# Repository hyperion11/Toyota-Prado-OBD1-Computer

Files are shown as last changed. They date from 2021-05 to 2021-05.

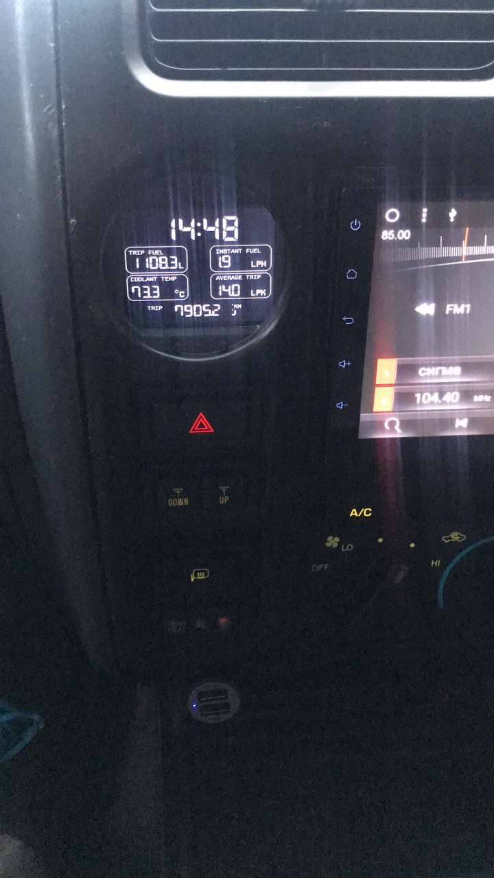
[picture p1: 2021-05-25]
source/TOBD1_STM32/problems1.jpg

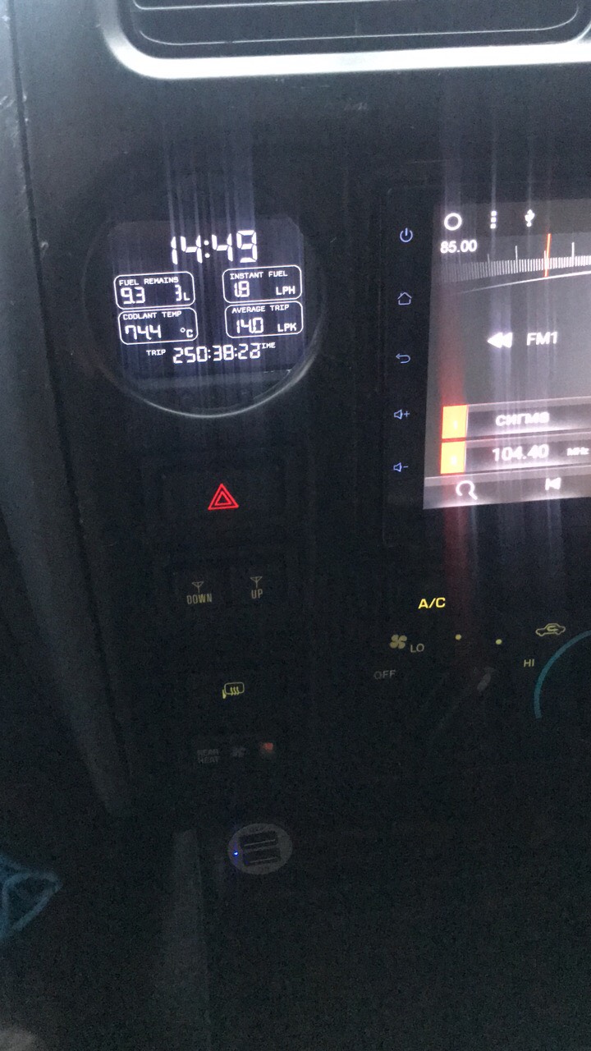
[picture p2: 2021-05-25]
source/TOBD1_STM32/problems2.jpg

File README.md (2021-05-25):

# Toyota-Prado-OBD1-Computer
OBD1 Car computer for Toyota land Cruiser Prado 90 95 1997-2002 5VZ-FE or 3RZ-FE engine

For "Thanks!" you can give me a "coffee" :)

https://www.tinkoff.ru/rm/degtyarev.aleksey35/kHApi80257

or

https://paypal.me/alekseydegtyarev1986?locale.x=ru_RU

BILL OF MATERIALS:

Maple Mini STM32 Dev board http://alii.pub/5snybc

2.4' ILI9341 SPI TFT Screen with flex cable w\o touch http://alii.pub/5snyhd

Capacitors:
22uF 0805 5pcs
http://alii.pub/5snzpw

1uF 0805 2pcs
http://alii.pub/5snzpw

0.1uF 0805 7pcs
http://alii.pub/5snzpw

3.3nF 0805 1pcs
http://alii.pub/5snzpw

100uF 0805 1pcs
http://alii.pub/5snzvc

Diode DO214
http://alii.pub/5so00s

ADC    B4B-ZRROUND           B4B-ZRROUND            B4B-ZR                JST-ZH Connector                                                                                       

BT2                          BATTERY                BATTCOM_20MM_VERTICAL Battery - Single Cell                                                                                 

PTC Fuse 1206 0.7-1A
http://alii.pub/5so034
 
FRAM MB85RC04VPNF 3.3v
http://alii.pub/5so077

LN6206                       MCP1700                SOT23                                                                                                                     LN6206P302MR-G                                                                                                                                                                                                      
Q1     PDTC143XT             MUN2211T1              SC59-BEC              NPN Bias Resistor Transistor                                                                                                                0                                                                                                                                                                           
Q2     PDTA143ZT             MUN2111T1              SC59-BEC              PNP Bias Resistor Transistor                                                                                                                0                                                                                                                                                                           
R1     33K                   R-EU_R0805             R0805                 RESISTOR, European symbol                                                                                                                                                                                                                                                                                               
R3     4                     R-EU_R0805             R0805                 RESISTOR, European symbol                                                                                                                                                                                                                                                                                               
R4     PHOTORESPDV-P9        PHOTORESPDV-P9         PDV-P9XXX             Photoresistor                                                                                                                                                                                                                                                                                                           
R10    20K                   R-EU_R0805             R0805                 RESISTOR, European symbol                                                                                                                                                                                                                                                                                               
R11    6.8K                  R-EU_R0805             R0805                 RESISTOR, European symbol                                                                                                                                                                                                                                                                                               
R12    3.3K                  R-EU_R0805             R0805                 RESISTOR, European symbol                                                                                                                                                                                                                                                                                               
R13    10K                   R-EU_R0805             R0805                 RESISTOR, European symbol                                                                                                                                                                                                                                                                                               
R31    4.7K                  R-EU_R0805             R0805                 RESISTOR, European symbol                                                                                                                                                                                                                                                                                               
R32    4.7K                  R-EU_R0805             R0805                 RESISTOR, European symbol                                                                                                                                                                                                                                                                                               
R38    100                   R-EU_R0805             R0805                 RESISTOR, European symbol                                                                                                                                                                                                                                                                                               
RN1    10K                   RN2_EU-4               CTS-744*083           Chip Resistor Array's from various manufactures                                                     CRA064RJ10K0E04Z                                                                                                                                                                                                    
RN2    2.2K                  RN2_EU-4               CTS-744*083           Chip Resistor Array's from various manufactures                                                     CRA064RJ10K0E04Z                                                                                                                                                                                                    
RN3    10K                   RN2_EU-4               CTS-744*083           Chip Resistor Array's from various manufactures                                                     CRA064RJ10K0E04Z                                                                                                                                                                                                    
RN4    2.2K                  RN2_EU-4               CTS-744*083           Chip Resistor Array's from various manufactures                                                     CRA064RJ10K0E04Z                                                                                                                                                                                                    
S1     DTSM-6                DTSM-6                 DTSM-6                                                                                                                                                                                                                                                                                                                                        
S2     DTSM-6                DTSM-6                 DTSM-6                                                                                                                                                                                                                                                                                                                                        
S3     DTSM-6                DTSM-6                 DTSM-6                                                                                                                                                                                                                                                                                                                                        
S4     DTSM-6                DTSM-6                 DTSM-6                                                                                                                                                                                                                                                                                                                                        
S5     DTSM-6                DTSM-6                 DTSM-6                                                                                                                                                                                                                                                                                                                                        
SERIAL B4B-ZRROUND           B4B-ZRROUND            B4B-ZR                JST-ZH Connector                                                                                                                                                                                                                                                                                                        
SG2    F/QMBIII              F/QMBIII               F/QMBIII              BUZZER Source: Buerklin                                                                                                unknown    unknown   1                                                                                                                                                                                                                                                                                                                          
U$2    JUSHUOAFC08-S18FCA-00 JUSHUOAFC08-S18FCA-00  JUSHUOAFC08-S18FCA-00                                                                                                     AFC08-S18FCA-00                                                                                                                                                                                                     
U$3    main                  B5B-ZRLONG             B5B-ZR-LONG           JST-ZH Connector                                                                                                                                                                                                                                                                                                        
U$4    MINI-DC-DC-3AV        MINI-DC-DC-3AV         MINI-DC-DC-3AV                                                                                                                                                                                                                                                                                                                                
U$5    ADC-4CH-ADS1115       ADC-4CH-ADS1115        ADC-4CH-ADS1115       4 Channel 16-Bit Analog-to-Digital Converter based on ADS1115 chip

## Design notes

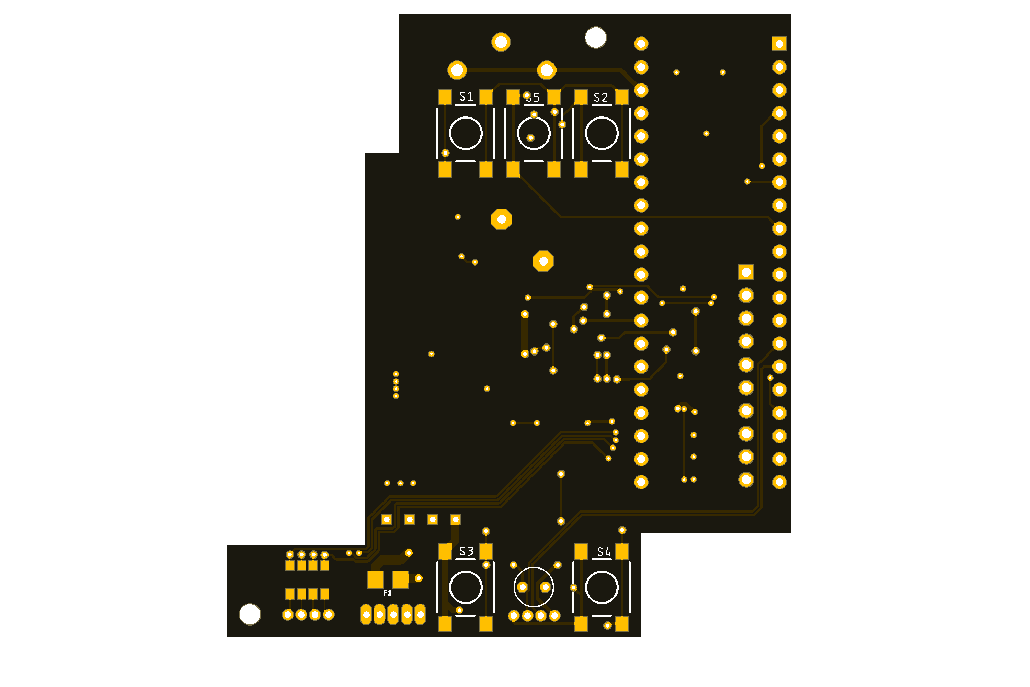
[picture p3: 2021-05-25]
Schematic/v2.4/TOBD_STM32b.png

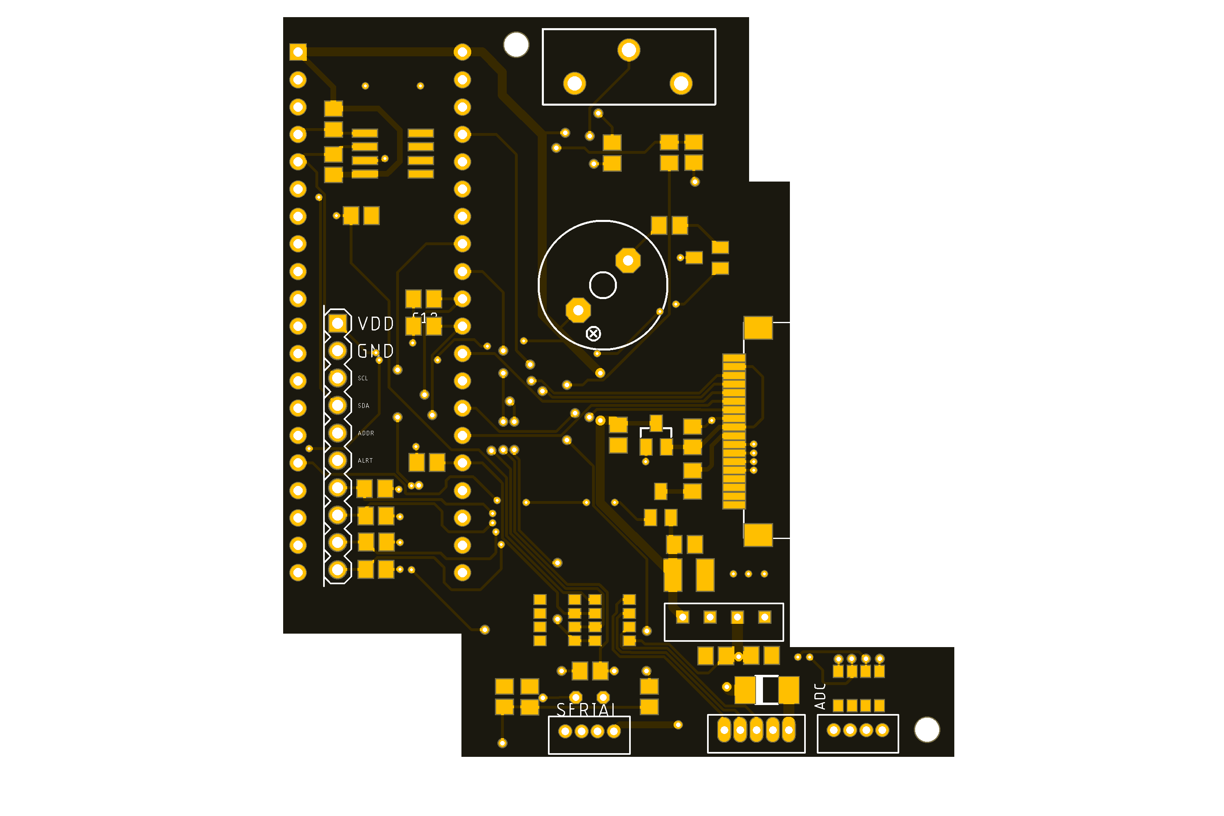
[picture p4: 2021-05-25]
Schematic/v2.4/TOBD_STM32е.png

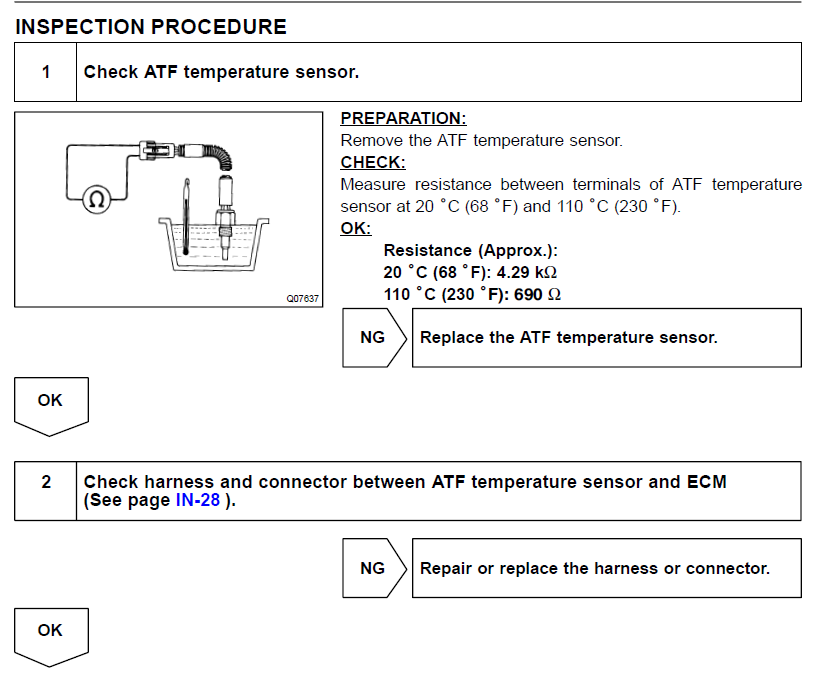
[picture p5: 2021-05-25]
source/TOBD1_STM32/atf_temp_sensor_2.png

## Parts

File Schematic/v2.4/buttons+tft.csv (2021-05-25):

C2 | 1uF | C-EUC0805 | C0805 | CAPACITOR, European symbol |  | Samsung Electro-Mechanics | CL21F105ZOFNNNE |  |  | 88 | C | https://lcsc.com/product-detail/Multilayer-Ceramic-Capacitors-MLCC-SMD-SMT_SAMSUNG_CL21F105ZOFNNNE_1uF-105-80-20-16V_C16834.html
C8 | 0.1uF | C-EUC0805 | C0805 | CAPACITOR, European symbol |  | Samsung Electro-Mechanics | CL21F104ZBCNNNC |  |  | 88 | C | https://lcsc.com/product-detail/Multilayer-Ceramic-Capacitors-MLCC-SMD-SMT_SAMSUNG_CL21F104ZBCNNNC_100nF-104-80-20-50V_C1760.html
C9 | 100uF | C-EUC1210K | C1210K | CAPACITOR, European symbol | C88154 | Murata Electronics | GRM32ER60J107ME20L |  |  |  |  | https://lcsc.com/product-detail/Multilayer-Ceramic-Capacitors-MLCC-SMD-SMT_muRata_GRM32ER60J107ME20L_100uF-107-20-6-3V_C88154.html
C10 | 22uF | C-EUC0805 | C0805 | CAPACITOR, European symbol | C45783 | Samsung Electro-Mechanics | CL21A226MAQNNNE |  |  |  |  | https://lcsc.com/product-detail/Multilayer-Ceramic-Capacitors-MLCC-SMD-SMT_Samsung-Electro-Mechanics-CL21A226MAQNNNE_C45783.html
C18 | 3.3nF | C-EUC0805 | C0805 | CAPACITOR, European symbol |  |  |  |  |  | 88 | C
IC4 | MB85RC04VPNF | 24C04ASN | SO-08 | Serial EEPROM |  |  |  | unknown | unknown | 0
LN6206 |  | MCP1700 | SOT23 |  |  |  | LN6206P332MR-G
RN1 | 10K | RN2_EU-4 | CTS-744*083 | Chip Resistor Array's from various manufactures |  |  | CRA064RJ10K0E04Z
RN2 | 2.2K | RN2_EU-4 | CTS-744*083 | Chip Resistor Array's from various manufactures |  |  | CRA064RJ10K0E04Z
U$2 | JUSHUOAFC08-S18FCA-00 | JUSHUOAFC08-S18FCA-00 | JUSHUOAFC08-S18FCA-00 |  |  |  | AFC08-S18FCA-00

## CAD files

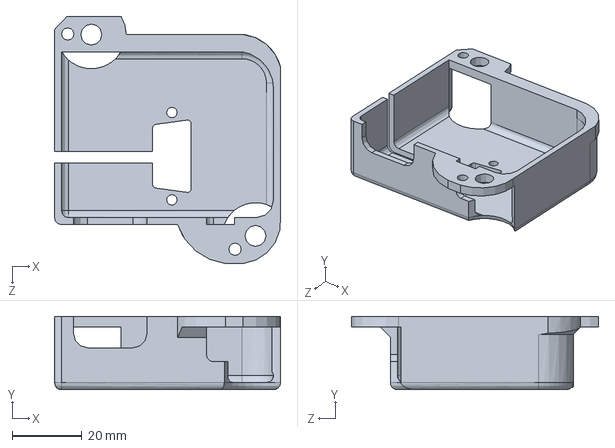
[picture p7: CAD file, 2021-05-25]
BK Model/Assem2.SLDASM
64.7 x 21.0 x 70.7 mm

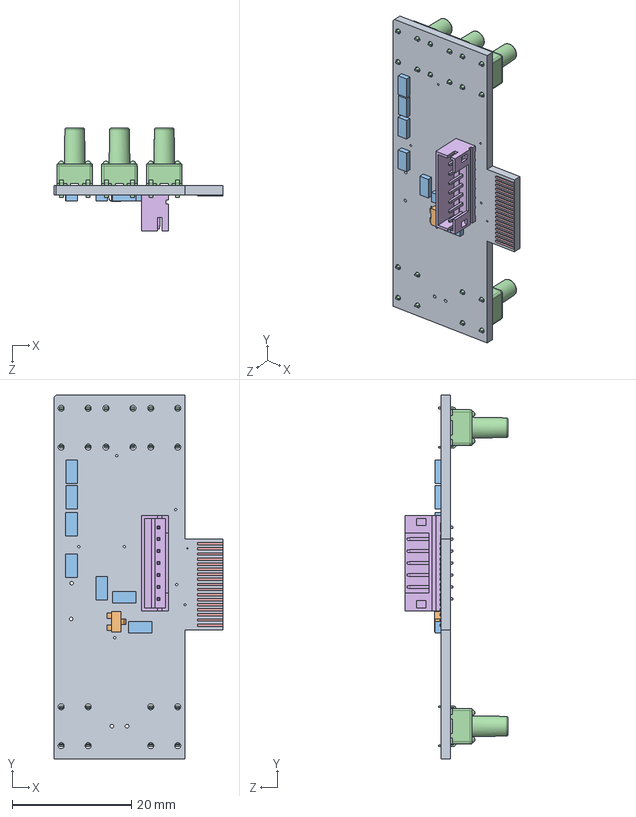
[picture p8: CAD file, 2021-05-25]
BK Model/buttons+tft.SLDASM
28.3 x 61.0 x 17.2 mm
buttons+tft
sot23_4210037
R0805_R0805 x 7
Tact DIP 6x6 x 5
18x08
Header Socket 2_0 7x

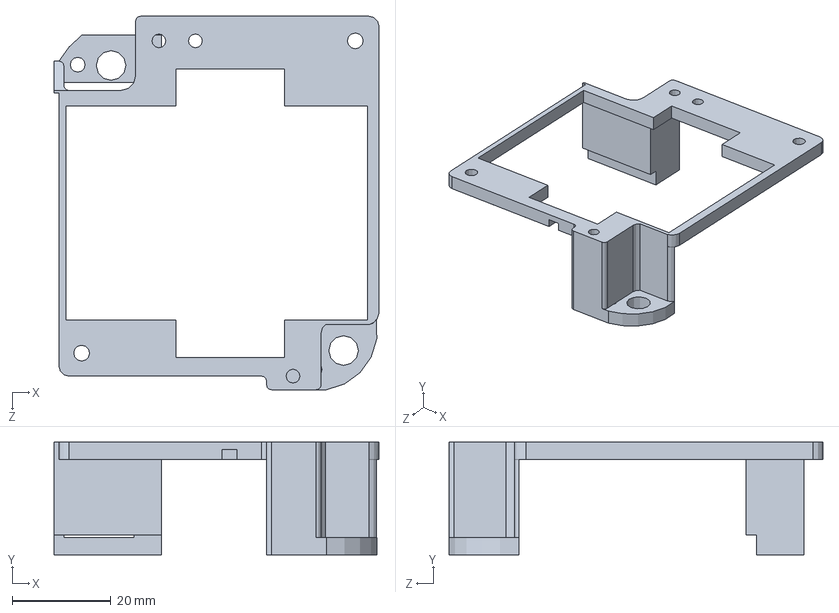
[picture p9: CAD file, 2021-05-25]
BK Model/main_box.SLDPRT
65.7 x 22.8 x 75.5 mm

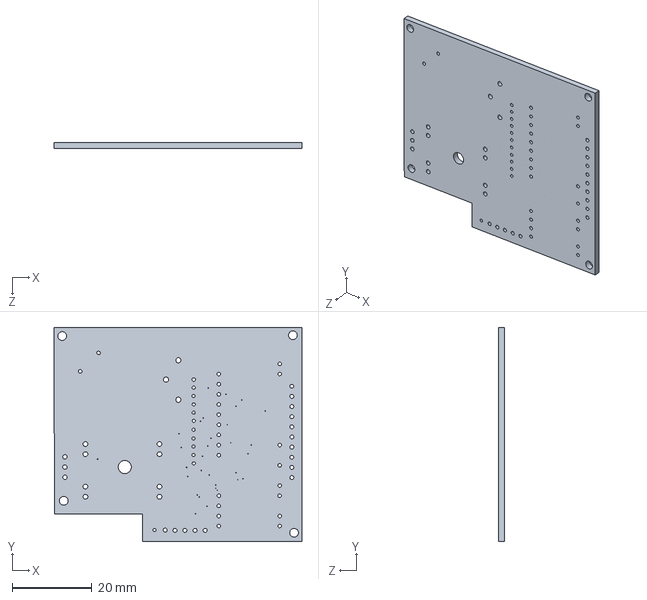
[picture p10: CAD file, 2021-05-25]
BK Model/pcb_top.SLDASM
62.1 x 53.7 x 1.60 mm

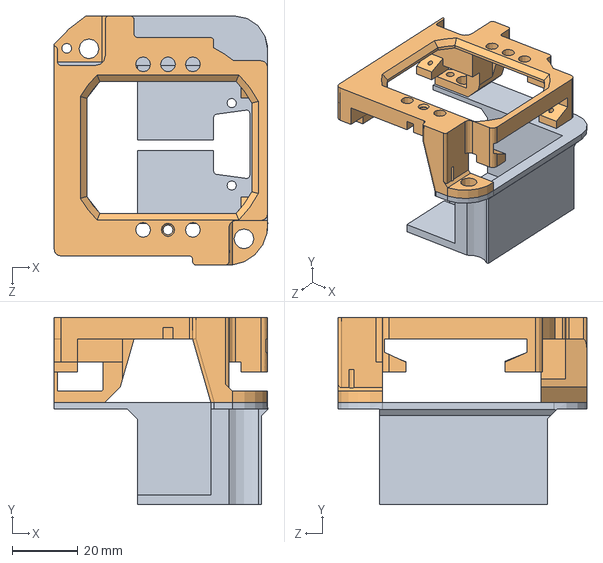
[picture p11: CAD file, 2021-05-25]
BK Model/Assem1.SLDASM
64.8 x 56.8 x 75.5 mm
крепеж_дисплея_top_v2.3
крепеж_дисплея_v2.3

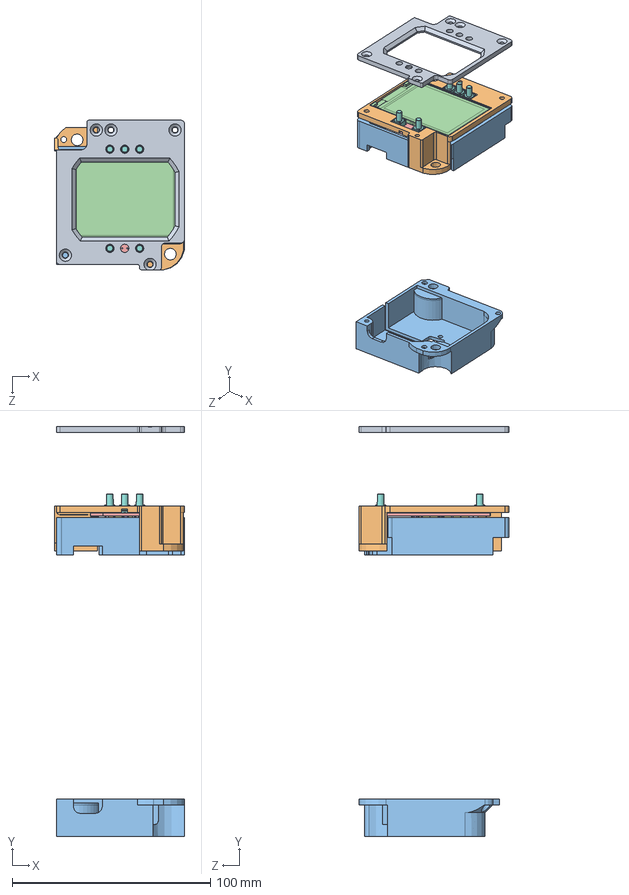
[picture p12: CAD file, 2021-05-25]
BK Model/Assem3.SLDASM
65.8 x 206.7 x 75.5 mm
front_shield
main_box
pcb_shield
2.4in TFT(Without Glass)- Reverse Mount
buttons+tft
sot23_4210037
R0805_R0805 x 7
Tact DIP 6x6 x 5
18x08
Header Socket 2_0 7x
крепеж_дисплея_top_v2.4_clean_remake

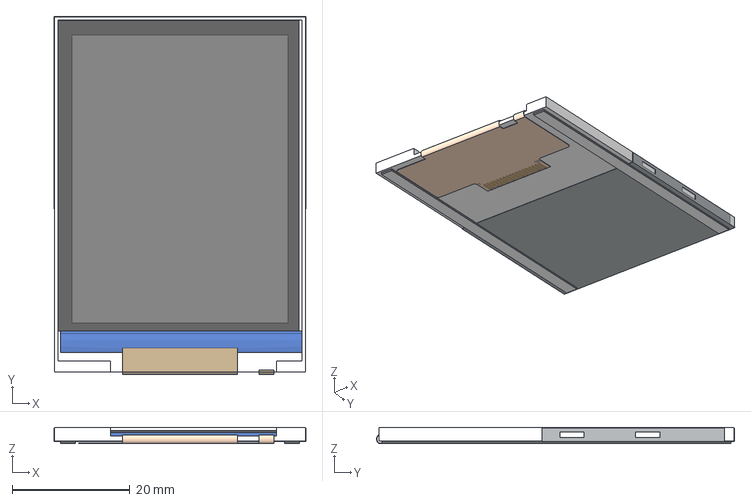
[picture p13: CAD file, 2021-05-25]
BK Model/2-4in-tft-module-1.snapshot.10/2.4in TFT(Without Glass)- Tucked Cable.stp
42.7 x 60.8 x 2.74 mm

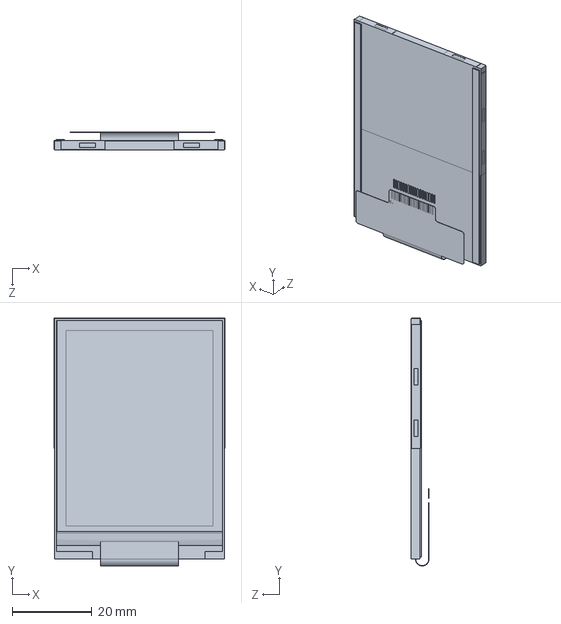
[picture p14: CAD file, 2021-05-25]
BK Model/2.4in TFT(Without Glass)- Reverse Mount.SLDPRT
42.7 x 62.1 x 4.60 mm

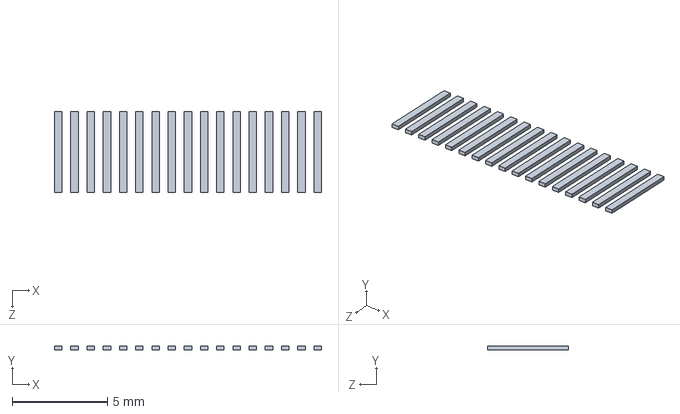
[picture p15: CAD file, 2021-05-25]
BK Model/18x08.SLDPRT
14.0 x 0.2 x 4.23 mm

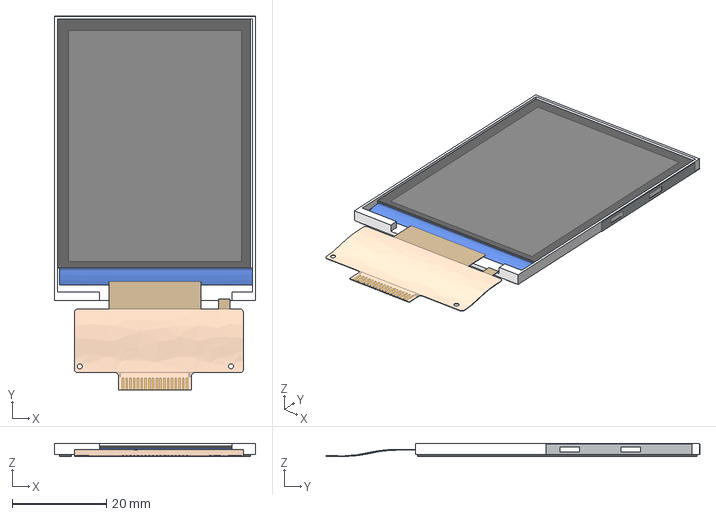
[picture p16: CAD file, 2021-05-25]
BK Model/2-4in-tft-module-1.snapshot.10/2.4in TFT(Without Glass)- Flat Mount.stp
42.7 x 79.4 x 2.74 mm

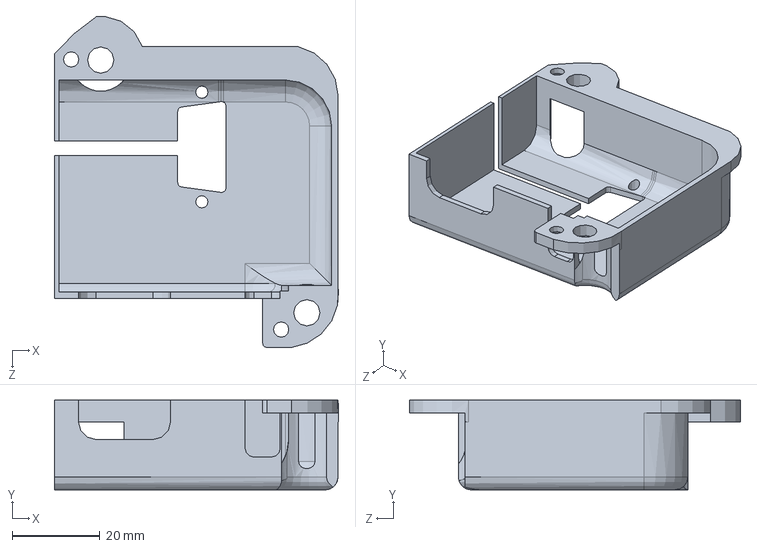
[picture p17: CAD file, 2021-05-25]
BK Model/крепеж_дисплея_top_v2.4.SLDPRT
64.8 x 20.5 x 75.5 mm

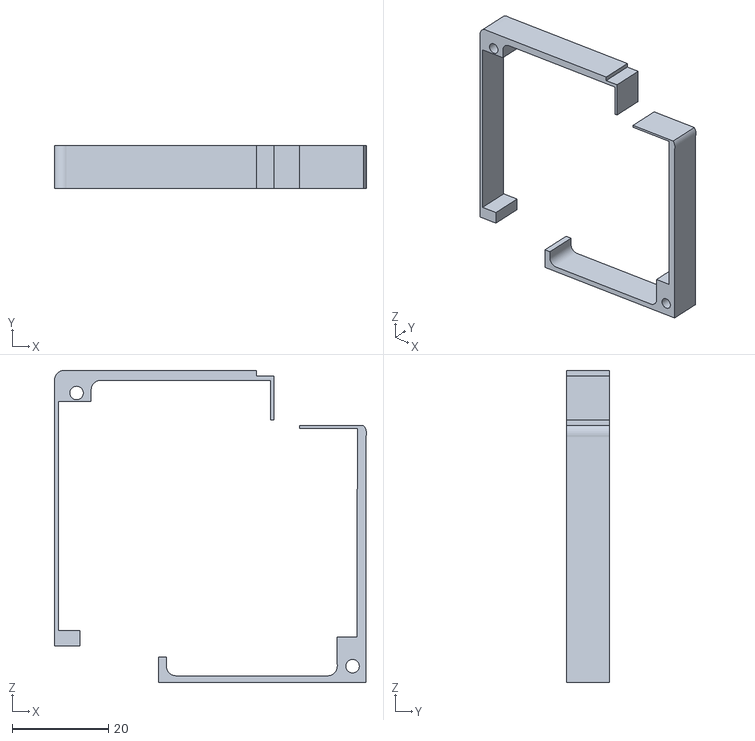
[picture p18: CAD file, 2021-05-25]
BK Model/2.STL
64.8 x 9.00 x 64.8

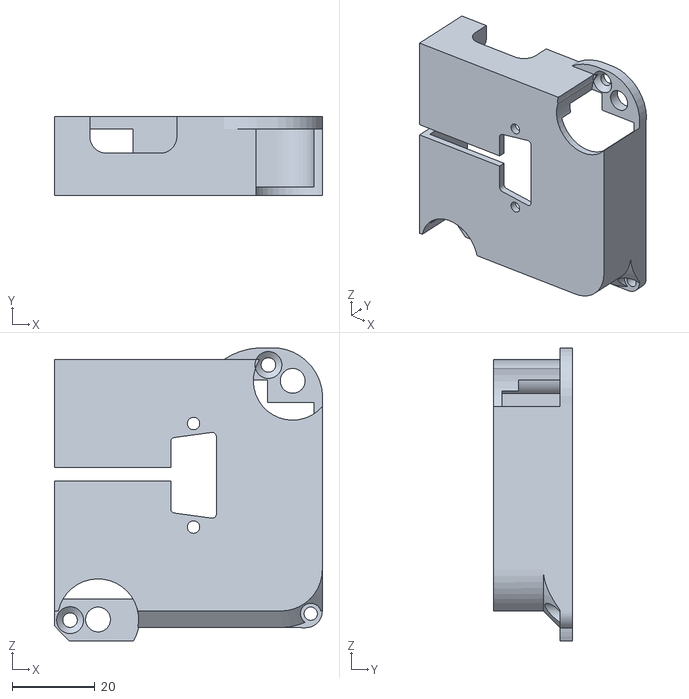
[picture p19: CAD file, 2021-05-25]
BK Model/1.STL
64.8 x 19.0 x 70.7

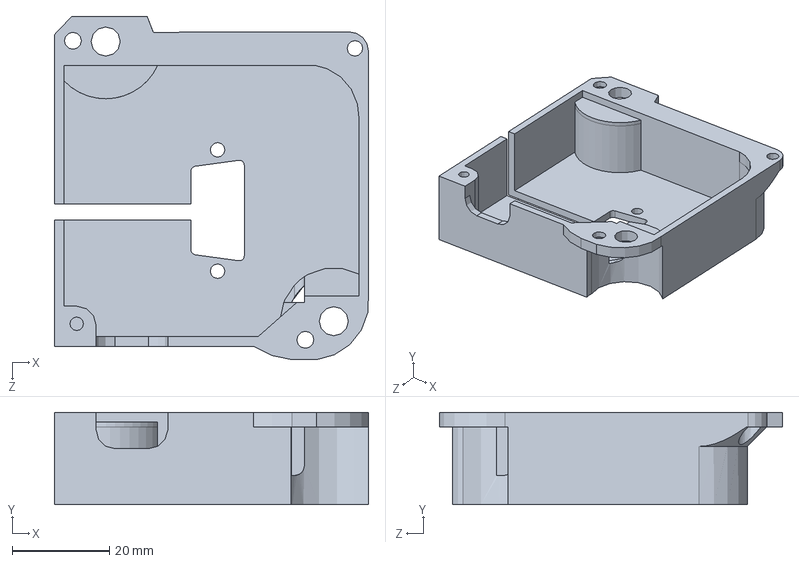
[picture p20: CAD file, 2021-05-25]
BK Model/крепеж_дисплея_top_v2.4_clean_remake.SLDPRT
64.7 x 19.0 x 70.7 mm

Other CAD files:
BK Model/2-4in-tft-module-1.snapshot.10/2.4in TFT(Without Glass)- Reverse Mount.stp
BK Model/крепеж_дисплея_v2.3.STEP
BK Model/крепеж_дисплея_1_v4.SLDPRT
BK Model/front_shield.SLDPRT
BK Model/front_shield.STL
BK Model/main_box.STL
BK Model/pcb_shield.SLDPRT
BK Model/pcb_shield.STL
BK Model/крепеж_дисплея_1_v1.SLDPRT
BK Model/крепеж_дисплея_1_v1.STL
BK Model/крепеж_дисплея_1_v2.SLDPRT
BK Model/крепеж_дисплея_1_v2.STL
BK Model/крепеж_дисплея_1_v3.SLDPRT
BK Model/крепеж_дисплея_1_v3.STL
BK Model/крепеж_дисплея_1_v4.STL
BK Model/крепеж_дисплея_top_v2.2.SLDPRT
BK Model/крепеж_дисплея_top_v2.2.STL
BK Model/крепеж_дисплея_top_v2.3.SLDPRT
BK Model/крепеж_дисплея_top_v2.3.STL
BK Model/крепеж_дисплея_top_v2.4.STL
BK Model/крепеж_дисплея_top_v2.4_clean_remake.STL
BK Model/крепеж_дисплея_v2.1.SLDPRT
BK Model/крепеж_дисплея_v2.1.STL
BK Model/крепеж_дисплея_v2.2.SLDDRW
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

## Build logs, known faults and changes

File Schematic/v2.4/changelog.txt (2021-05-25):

v 2.1
1. Пофикшен земляной пин для платы TFT 
2. Перенесен пин BUT_ARRAY из под DC-DC
3. Фикс reset pina tft дисплея

v2.2
1. Добавлен фоторезистор на плату кнопок

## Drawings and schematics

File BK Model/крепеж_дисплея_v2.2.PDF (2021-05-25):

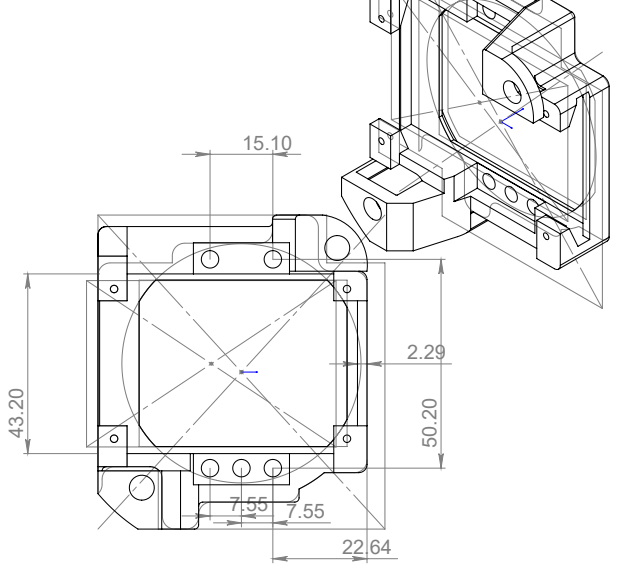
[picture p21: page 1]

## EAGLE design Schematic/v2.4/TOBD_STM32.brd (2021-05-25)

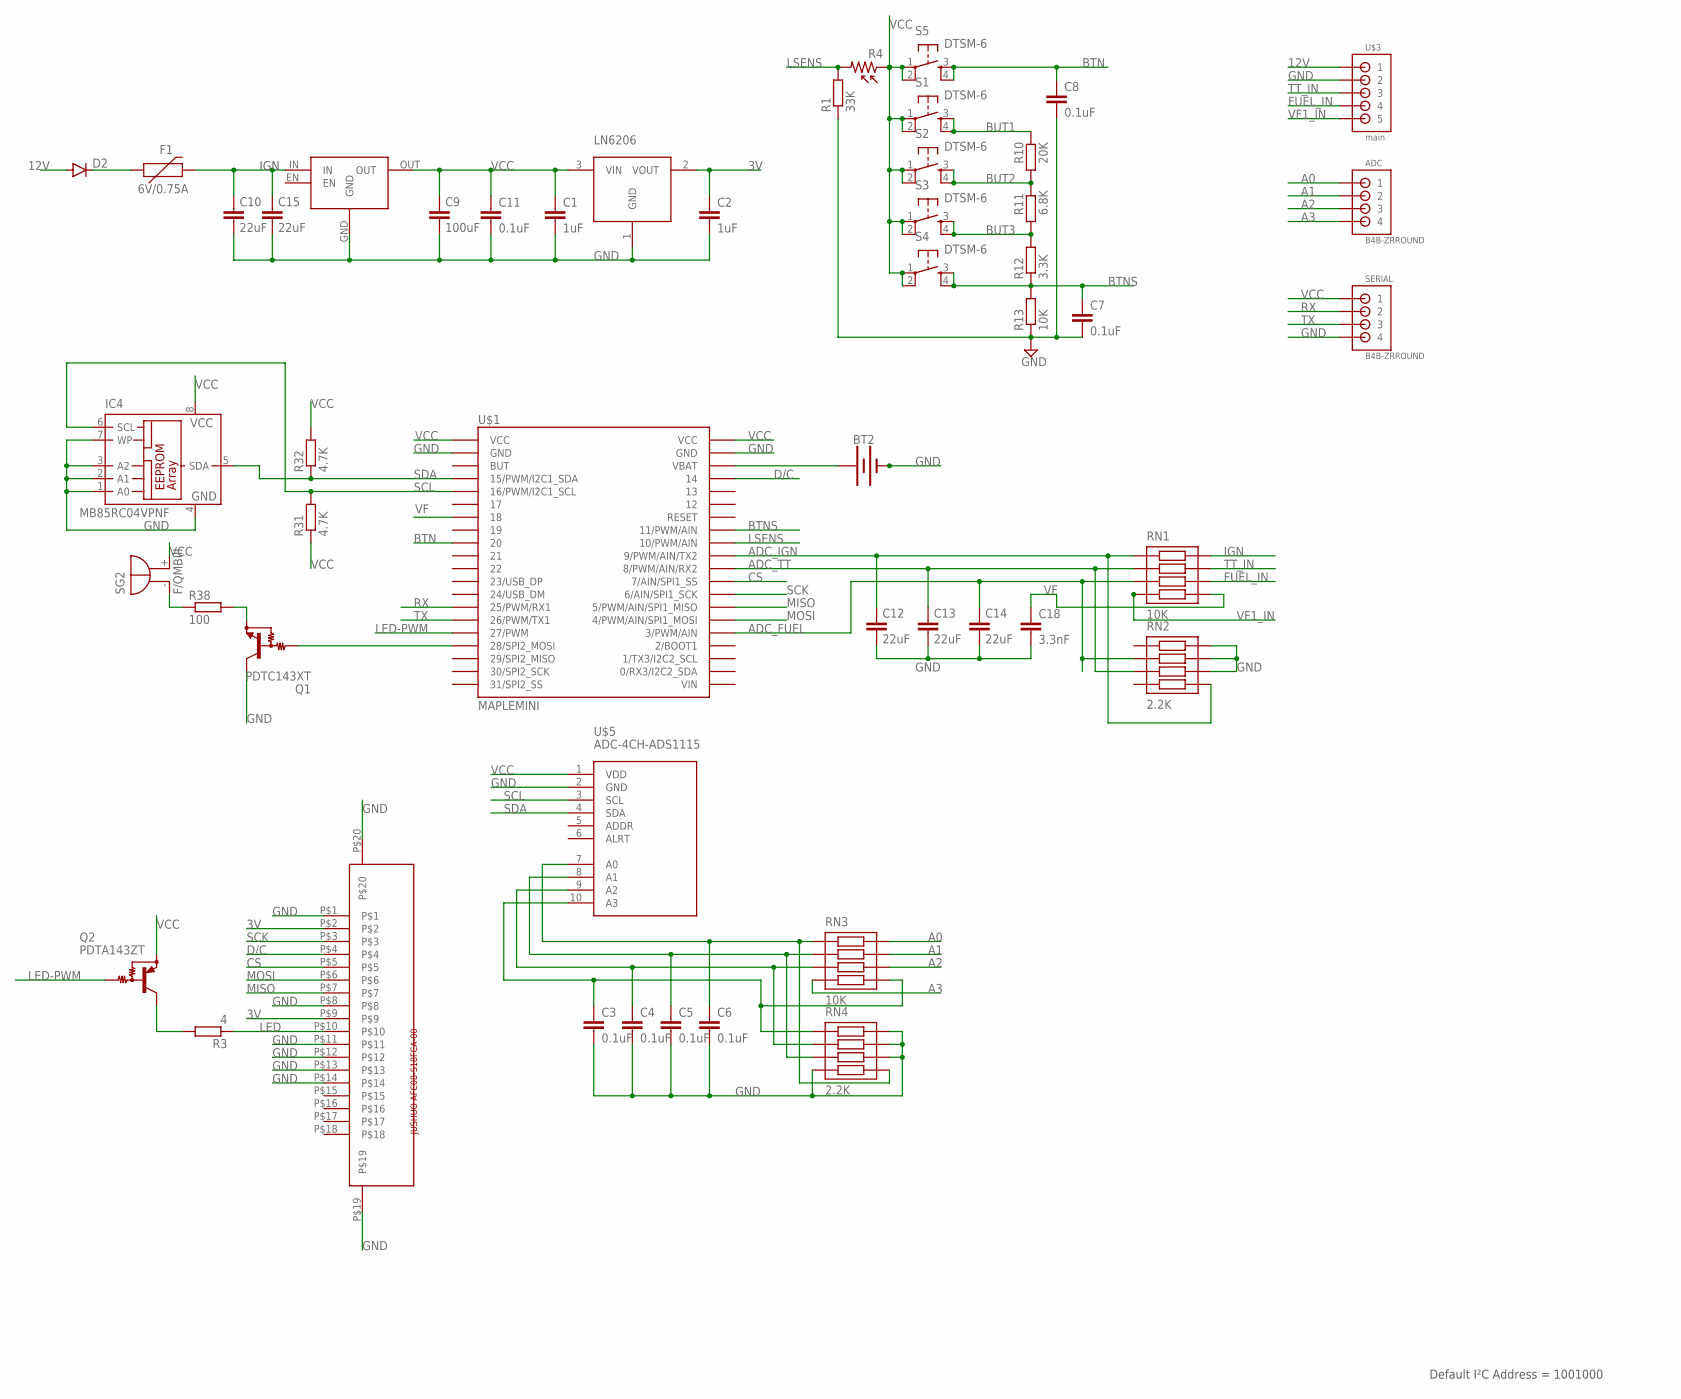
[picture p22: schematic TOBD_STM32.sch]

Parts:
ADC: B4B-ZRROUND; B4B-ZR
BT2: BATTERY; BATTCOM_20MM_VERTICAL
C1, C2: 1uF; C0805; MPN CL21F105ZOFNNNE
C3, C4, C5, C6, C7, C8, C11: 0.1uF; C0805; MPN CL21F104ZBCNNNC
C9: 100uF; C1210K; MPN GRM32ER60J107ME20L; LCSC C88154
C10, C12, C13, C14, C15: 22uF; C0805; MPN CL21A226MAQNNNE; LCSC C45783
C18: 3.3nF; C0805; MPN CL21B332KBANNNC
D2: DIODE-DO-214AC; DO-214AC
F1: 6V/0.75A; 1206
IC4: MB85RC04VPNF; SO-08
LN6206: MCP1700; SOT23; MPN LN6206P302MR-G
Q1: PDTC143XT; SC59-BEC
Q2: PDTA143ZT; SC59-BEC
R1: 33K; R0805
R3: 4; R0805
R4: PHOTORESPDV-P9; PDV-P9XXX
R10: 20K; R0805
R11: 6.8K; R0805
R12: 3.3K; R0805
R13: 10K; R0805
R31, R32: 4.7K; R0805
R38: 100; R0805
RN1, RN3: 10K; CTS-744*083; MPN CRA064RJ10K0E04Z
RN2, RN4: 2.2K; CTS-744*083; MPN CRA064RJ10K0E04Z
S1, S2, S3, S4, S5: DTSM-6
SERIAL: B4B-ZRROUND; B4B-ZR
SG2: F/QMBIII
U$1: MAPLEMINI; 20-DIP
U$2: JUSHUOAFC08-S18FCA-00; MPN AFC08-S18FCA-00
U$3: main; B5B-ZR-LONG
U$4: MINI-DC-DC-3AV
U$5: ADC-4CH-ADS1115

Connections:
3V: C2.1, LN6206.2 (VOUT), U$2.P$2, U$2.P$9
12V: D2.A, U$3.1
A0: ADC.1, RN3.5 (8)
A1: ADC.2, RN3.6 (7)
A2: ADC.3, RN3.7 (6)
A3: ADC.4, RN3.8 (4)
ADC_FUEL: C14.1, RN1.2 (3), RN2.3 (2), U$1.25 (3/PWM/AIN)
ADC_IGN: C12.1, RN1.4 (1), RN2.1 (5), U$1.31 (9/PWM/AIN/TX2)
ADC_TT: C13.1, RN1.3 (2), RN2.2 (3), U$1.30 (8/PWM/AIN/RX2)
BTN: C8.1, S5.3, S5.4, U$1.9 (20)
BTNS: C7.1, R12.1, R13.2, S4.3, S4.4, U$1.33 (11/PWM/AIN)
BUT1: R10.2, S1.3, S1.4
BUT2: R10.1, R11.2, S2.3, S2.4
BUT3: R11.1, R12.2, S3.3, S3.4
CS: U$1.29 (7/AIN/SPI1_SS), U$2.P$5
D/C: U$1.37 (14), U$2.P$4
FUEL_IN: RN1.7 (6), U$3.4
GND: BT2.3 (-), C1.2, C2.2, C3.2, C4.2, C5.2, C6.2, C7.2, C8.2, C9.2, C10.2, C11.2, C12.2, C13.2, C14.2, C15.2, C18.2, IC4.1 (A0), IC4.2 (A1), IC4.3 (A2), IC4.4 (GND), IC4.7 (WP), LN6206.1 (GND), Q1.C, R1.1, R13.1, RN2.5 (8), RN2.6 (7), RN2.7 (6), RN4.5 (8), RN4.6 (7), RN4.7 (6), RN4.8 (4), SERIAL.4, U$1.2 (GND), U$1.39 (GND), U$2.P$1, U$2.P$8, U$2.P$11, U$2.P$12, U$2.P$13, U$2.P$14, U$2.P$19, U$2.P$20, U$3.2, U$4.GND, U$5.2 (GND)
IGN: C10.1, C15.1, F1.2, RN1.5 (8), U$4.IN
LED: R3.1, U$2.P$10
LED-PWM: Q2.B, U$1.16 (27/PWM)
LSENS: R1.2, R4.2, U$1.32 (10/PWM/AIN)
MISO: U$1.27 (5/PWM/AIN/SPI1_MISO), U$2.P$7
MOSI: U$1.26 (4/PWM/AIN/SPI1_MOSI), U$2.P$6
unnamed: R38.1, SG2.- (+)
unnamed: Q2.C, R3.2
unnamed: D2.C, F1.1
unnamed: C6.1, RN3.4 (1), RN4.1 (5), U$5.7 (A0)
unnamed: C5.1, RN3.3 (2), RN4.2 (3), U$5.8 (A1)
unnamed: C4.1, RN3.2 (3), RN4.3 (2), U$5.9 (A2)
unnamed: C3.1, RN3.1 (5), RN4.4 (1), U$5.10 (A3)
unnamed: Q1.B, U$1.17 (28/SPI2_MOSI)
unnamed: Q1.E, R38.2
RX: SERIAL.2, U$1.14 (25/PWM/RX1)
SCK: U$1.28 (6/AIN/SPI1_SCK), U$2.P$3
SCL: IC4.6 (SCL), R31.2, U$1.5 (16/PWM/I2C1_SCL), U$5.3 (SCL)
SDA: IC4.5 (SDA), R32.1, U$1.4 (15/PWM/I2C1_SDA), U$5.4 (SDA)
TT_IN: RN1.6 (7), U$3.3
TX: SERIAL.3, U$1.15 (26/PWM/TX1)
VBAT1: BT2.1 (+), BT2.2 (+), U$1.38 (VBAT)
VCC: C1.1, C9.1, C11.1, IC4.8 (VCC), LN6206.3 (VIN), Q2.E, R4.1, R31.1, R32.2, S1.1, S1.2, S2.1, S2.2, S3.1, S3.2, S4.1, S4.2, S5.1, S5.2, SERIAL.1, SG2.+ (-), U$1.1 (VCC), U$1.40 (VCC), U$4.OUT, U$5.1 (VDD)
VF: C18.1, RN1.1 (5), U$1.7 (18)
VF1_IN: RN1.8 (4), U$3.5

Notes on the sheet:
Default I²C Address = 1001000

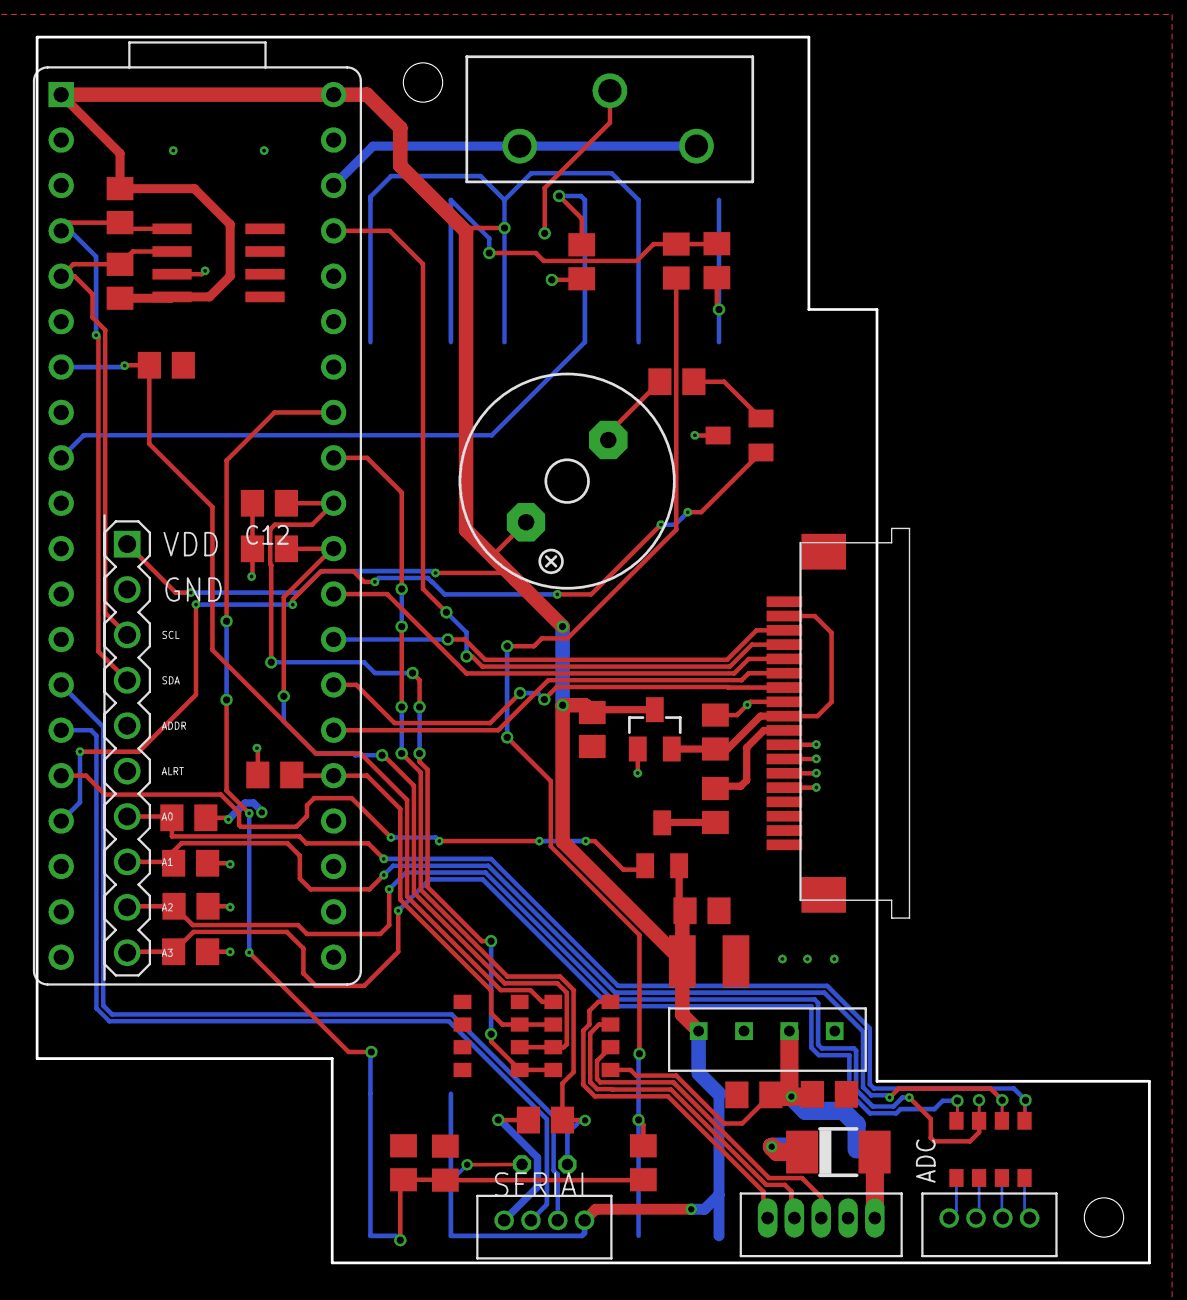
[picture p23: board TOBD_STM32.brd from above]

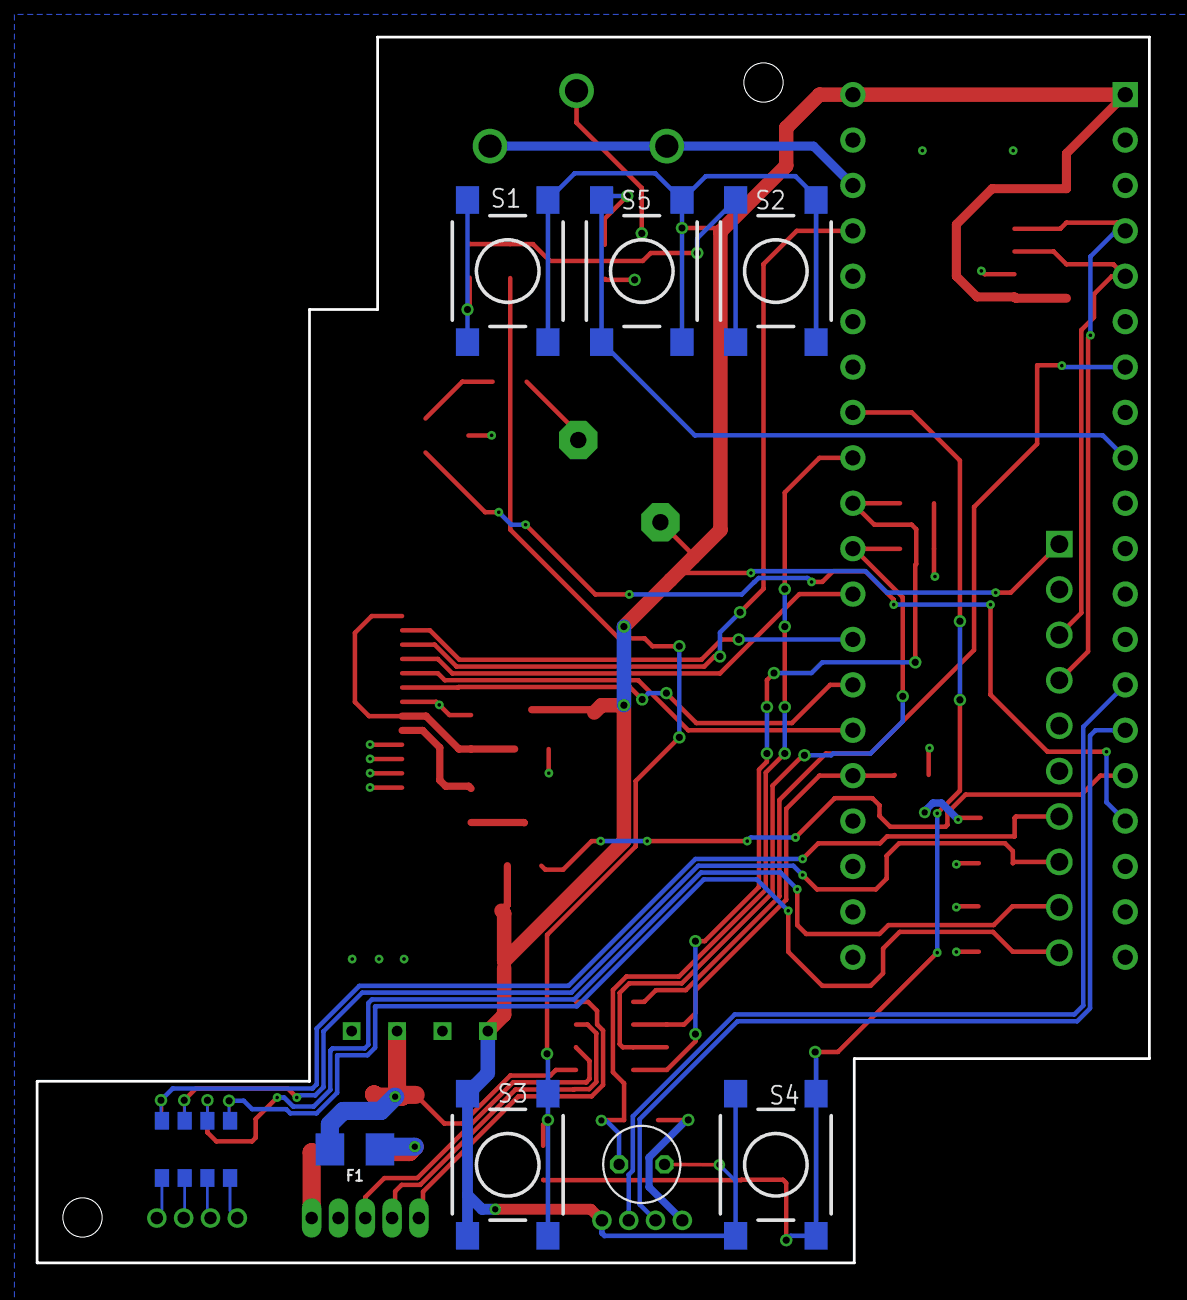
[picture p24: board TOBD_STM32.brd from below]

Board: 2 copper layers, 62.2 x 68.6 mm, 50 parts (8 on the bottom side), 43 nets.

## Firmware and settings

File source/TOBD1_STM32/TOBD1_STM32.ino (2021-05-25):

//todo
//####перерисовка 3го экрана кривая -  работает
//####нету сброса полного километража  -работает
//!!!!добавить всетаки отдельный километраж который не будет сбрасываться.  -проверить
//####индикатор акпп не показывает нейтраль    -  проверить фикс - не показывается 1я передача - проверить фикс - все работает
//####редко обновляется индикатор среднего расхода на главной панели - проверить фикс - мелькают большие цифры - проверить фикс - все работает
//####добавить схему белый тест на черном фоне - готово
//добавить экран с датой и временем
//####добавить калибровку производительности форсунок - готово
//наладить форматирование на экране настроек
//допилить измерение уровня топлива
//#####LPH не всегда обновляется и слишком много стирается справа
//#####сместить вниз и вправо весь первый экран - проверить
//#####сместить вниз и вправо весь третий экран - проверить
//#####AVG расход не всегда обновляется - проверить
//#####VF изменил диапазон от 0до5В - старая формула была верная. Вернул обратно старую формулу
//######изменил работу подсветки - проверить -
//######добавил счетчик стартов устройства. Добавил счетчик записей в FRAM. Проверить работу.
//#####уменьшил шрифт часов. Проверить центровку.
//#####добавил процентное отображение топливных коррекций
//7.12.2018 Поправил очистку экрана для Trip Fuel/Fuel Remaind > 1000
//          поправил ввывод времени поездки
//9.12.2018 Попробовал сделать коррекцию времени. setbktime, getbktime, timecorrection, FRAM.read(50, DRIFT_DUR);









#define RTC_BTP_IN_FRAM //RTC_BKP_IN_BKP
#define DEBUG_SERIAL_OUTPUT
#define DEBUG_RTC
//#define DEBUG_SCREEN
#define VZ   // VZ - 5VZ; RZ - 3RZ
//#define ADS1115 //Внешний ADC на 4 канала
//HW VERSIONS:
//2  -  PCB 2.2 - TT Делитель 5.6+3k = 2.87 9В максимум
//3  -  PCB 2.3 - TT Делитель 5.6+1.5k = 4.73 15В максимум
#define HW_VERSION 2
#define SW_VERSION 2.2
#include "defines.h"
#include "variables.h"
#include "extra.h"
#include "src\FRAM24CXX\FRAM24CXX.h"
#include "SPI.h"
#include <RTClock.h>
#include "src\MD_KeySwitch\MD_KeySwitch.h"
#include "src\rtadjust\rtadjust.h"
//#include <Adafruit_ILI9341_STM.h>

#include <Adafruit_ILI9341.h>           //     <<<<<<<<<<<<<<
#include <Adafruit_GFX.h>            //<<<<<<<<<<<<<

#include "src\CPMonoP9pt7b.h"
#include "src\CPMono_L6pt7b.h"
#include "src\CPMono_L13pt7b.h"
#include "src\DSEG7ModernMini-Bold13pt7b.h"
#include "src\DSEG7ModernMini-Bold25pt7b.h"

//конструкторы
Adafruit_ILI9341 tft = Adafruit_ILI9341(TFT_CS, TFT_DC); // Use hardware SPI
FRAM24CXX FRAM(0x50, 4); //chipaddress, chipDensity
RTClock rt (RTCSEL_LSE);
tm_t tm;
MD_KeySwitch S(RESET_PIN, HIGH);


void setup() {
  Serial.begin(115200);
  Serial1.begin(115200);
  delay (300);
  Wire.begin();
  tft.begin();
  tft.fillScreen(ILI9341_RED);
  FRAM.begin();
  pinMode(ENGINE_DATA_PIN, INPUT); // VF1 PIN
  pinMode(TT_PIN, INPUT_ANALOG);
  pinMode(FUEL_PIN, INPUT_ANALOG);
  pinMode(VCC_PIN, INPUT_ANALOG);
  pinMode(BUTTON_ARRAY_PIN, INPUT_ANALOG);
  pinMode(TFT_LED_PIN, PWM);
  pinMode(LIGHT_SENSOR_PIN, INPUT_ANALOG);
  Serial.println("Pins attached");
  attachInterrupt(ENGINE_DATA_PIN, ChangeState, CHANGE); //setup Interrupt for data line
#if defined(DEBUG_SERIAL_OUTPUT)
  Serial.println("Interrrupt attached");
#endif
  S.begin();
  S.enableDoublePress(false);
  S.enableLongPress(true);
  S.enableRepeat(false);
  S.enableRepeatResult(false);
  S.setDoublePressTime(300);
  S.setLongPressTime(2000);
  //S.setDebounceTime(100);
  tft.setRotation(3);
  bkp_init();
  read_fram_data();
  tft_string ("   ENGINE:");
#if defined(VZ)
  tft_string ("   5VZ-FE");
#elif defined(RZ)
  tft_string ("   3RZ-FE");
#else
  tft_string ("   Unknown Engine");
#endif
  tft.print("HW VERSION: ");
  tft.println(HW_VERSION);
  tft.print("SW VERSION: ");
  tft.println(SW_VERSION, 1);

  delay (2000);
#if defined(DEBUG_SERIAL_OUTPUT)
  Serial.println("Buttons attached");
#endif
  CurrentDisplayIDX = 2; // set to display 2
  last_log_time = 0;
  t = millis();
  omm = rt.minute();
  start_count++;
  FRAM.write(41, start_count);
  writeHeader();
  isActive = false;
  ADC.index = 0;
  ADC.tt_in = 0;
  ADC.fuel_in = 0;
  ADC.vcc_in = 0;
  init_ = false;
#if defined(DEBUG_SERIAL_OUTPUT)
  Serial.println("INIT COMPLETE");
#endif
    adjtime();
} // END VOID SETUP

void loop(void) {
#if defined(DEBUG_RTC)
  if (Serial.available())
    processkey();
#endif
  if (millis() % 2 == 0)
  {
    readbuttons();     //каждые 2мс происходит чтение состояния кнопок
    backlightadjust(); //каждые 2мс оценивается яркость и корректируется
    if (ADC.index < 20)
    {
      ADC.vcc_in += analogRead(VCC_PIN) + VCC_DROP;
      ADC.fuel_in += analogRead(FUEL_PIN);
      ADC.index++;
    }
    if (ADC.tt_index < 100) {
      ADC.tt_in += analogRead(TT_PIN);
      ADC.tt_index++;
    }
    else ADC.is_ready = true;
  }
  if (millis() % 500 == 0 && ADC.is_ready == true) {
    ADC.tt_avg = ADC.tt_in / ADC.tt_index;
    TT.current = (int)(ADC.tt_avg * VREF_MEASURED * TT_PIN_DIVIDER / 4095.0  + 0.5);
    if (TT.last != TT.current) {
      show_current_gear(); //принудительная перерисовка
      TT.last = TT.current;
    }
    ADC.tt_index = 0;
    ADC.tt_in = 0;
    ADC.is_ready = false;
  }
  if ((ToyotaNumBytes > 0) && (CurrentDisplayIDX != 4))  {  // if found bytes
    if (flag.f_num == 3) {        //    ротация
      flag.isTrip = !flag.isTrip; //    данных
      flag.TripActive = false;    //     на
      flag.f_num = 0;             //    главном экране
    }                             //    раз в три новых
    flag.f_num++;                 //    пакета OBD данных
    getOBD();   //конвертация данных + оформление их в массив
    new_t = millis();
    if (new_t > t && OBDDATA[OBD_RPM] > 100 ) {// выполняем только  на работающем двигателе
      diff_t = new_t - t;
      cycle_obd_inj_dur = OBDDATA[OBD_RPM]  * Ncyl * (float)diff_t  * OBDDATA[OBD_INJ] / 120000.0; //Время открытых форсунок за 1 такт данных. В МС
      //форсунка срабатывает раз в 2 оборота КВ
      //время цикла мс в с. Получаем кол-во срабатываний за время цикла. Умножаем на время открытия форсунки, получаем время открытия 6 форсунок В МИЛЛИСЕКУНДАХ
      trip_inj_dur += cycle_obd_inj_dur;                                                              //Время открытых форсунок за поездку        В МС
      total_inj_dur += cycle_obd_inj_dur;                                                           //Время открытых форсунок за все время. EEPROM    В МС
      inj_dur_RO += cycle_obd_inj_dur;
      cycle_trip = (float)diff_t  * OBDDATA[OBD_SPD] / 3600000.0;  //расстояние пройденное за такт обд данных
      trip_km += cycle_trip;  //Полное пройденное расстояние. EEPROM. В КМ
      total_km += cycle_trip;       //электронный одометр. Хранится в еепром и не стирается кнопкой
      km_RO += cycle_trip;
      trip_time += diff_t;             //Время в пути в миллисекундах с момента включения
      total_time += diff_t;
      time_RO += diff_t;
      fuel.remains -= cycle_obd_inj_dur * Ls / 1000.0; //остаток в баке стал децл меньше
      t = new_t;//тест
      ADC.fuel_avg = ADC.fuel_in / ADC.index;
      fuel.volt = (float)analogRead(FUEL_PIN) * VREF_MEASURED * FUEL_PIN_DIVIDER / 4095.0;
      fuel.volt_avg = (float)ADC.fuel_avg * VREF_MEASURED * FUEL_PIN_DIVIDER / 4095.0;
      ADC.vcc_avg = ADC.vcc_in / ADC.index;
      logData();
      if (millis() - last_log_time > 60000) SaveToFram(); //запись данных каждую минуту
      if (OBDDATA[OBD_SPD] == 0 && flagNulSpeed == false) SaveToFram(); //запись данных при остановке
      if (OBDDATA[OBD_SPD] != 0) flagNulSpeed = false;     //начали двигаться - разрешаем запись
    }
    trip_fuel_consumption = trip_inj_dur  * Ls / 1000.0;    //потребление топлива за поездку в литрах
    total_fuel_consumption = total_inj_dur  * Ls / 1000.0;  //потребление топлива за все время. Из ЕЕПРОМ в литрах
    trip_avg_fuel_consumption = 100.0 * trip_fuel_consumption / trip_km; //средний расход за поездку
    total_avg_fuel_consumption = 100.0 * total_fuel_consumption / total_km;
    trip_avg_speed = trip_km  * 3600000.0 / (float)trip_time ;       //средняя скорость за поездку
    total_avg_spd = total_km * 3600000.0 / (float)total_time ;
    if (ADC.vcc_avg < 2317  || ADC.vcc_avg > 2767 )
    {
      if (alarms == true)
      {
        alarmscreen();
#if defined(DEBUG_SERIAL_OUTPUT)
        Serial.println("ALARM!!!");
        Serial.print("VCC: ");
        Serial.println(ADC.vcc_avg * VREF_MEASURED * VCC_PIN_DIVIDER / 4095.0, 2);
        Serial.print("VCC RAW: ");
        Serial.println(ADC.vcc_avg);
#endif
      }
      else
        drawScreenSelector();
    }
    else
      drawScreenSelector();
#if defined(DEBUG_SERIAL_OUTPUT)
    Serial.println("DEBUG MESSAGES: ");
    Serial.print("VCC: ");
    Serial.println(ADC.vcc_avg * VREF_MEASURED * VCC_PIN_DIVIDER / 4095.0, 2);
    Serial.print("TT: ");
    Serial.println(ADC.tt_avg * VREF_MEASURED * TT_PIN_DIVIDER / 4095.0, 2);
    Serial.print("FUEL: ");
    Serial.println(fuel.volt, 2);
#endif
    for (uint8_t i = 0; i < TOBD_ID_MAX; i++)
      OLDOBDDATA[i] = OBDDATA[i];
    for (uint8_t i = 0; i < TOBD_ID_MAX + 1; i++)
      OLDOBDFLAG[i] = OBDFLAG[i];
    ToyotaNumBytes = 0;     // reset the counter.
    ADC.fuel_in = 0;
    ADC.vcc_in = 0;
    ADC.index = 0;
  } // end if (ToyotaNumBytes > 0)
}


void drawScreenSelector(void) {
  if (CurrentDisplayIDX == 1)
    drawAllData();
  else if (CurrentDisplayIDX == 2)
    mainscreen();
  else if (CurrentDisplayIDX == 3)
    summary_screen();
  else if (CurrentDisplayIDX == 4)
    settings();
} // end drawScreenSelector()

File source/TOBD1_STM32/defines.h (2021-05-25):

#ifndef DEFINES_H
#define DEFINES_H

#define VREF_MEASURED 3.32              //Измеренное опорное напряжение с 3.3В стабилизатора

#if (HW_VERSION==2)
#define TT_PIN_DIVIDER 2.87
#elif (HW_VERSION==3)
#define TT_PIN_DIVIDER 4.73
#endif

#if defined (ADS1115)
#define ADS1115_A0_A1_DIVIDER 2
#define ADS1115_A2_A3_DIVIDER 4.73
#endif

#define FUEL_PIN_DIVIDER 4.73
#define VCC_PIN_DIVIDER 6.6
#define interval2 2                      //2ms Интервал
#define interval500 500
//#define SECOND_O2SENS  // Включение 2го сенсора кислорода для V движков
#define DEBUG_OUTPUT false // for debug option - swith output to Serial
//DEFINE пинов под входы-выходы
//ADC PIN's  3, 4, 5, 6, 7, 8, 9, 10, 11
//#define LED_PIN         33  //встроенный светодиод
#define FUEL_PIN           PB0  //D3-для датчика уровня топлива
#define TT_PIN             PA3  //D8-PA3 для сенсора ТТ АКПП
#define ENGINE_DATA_PIN    PB4  //D18-PB5-EXTI5 VF1 PIN
#define TFT_CS             PA4  //D7   //SS
#define TFT_DC             PC13 //D14
#define TFT_LED_PIN        PA8  //27 -PA2 для шим подсветки дисплея
#define LIGHT_SENSOR_PIN   PA1  //D10-PA1 Для фоторезистора
#define BUTTON_ARRAY_PIN   PA0  //D11-PA0 для массива из 4х кнопок
#define RESET_PIN          PA15  //D20 отдельно для кнопки сброса //2.1
#define VCC_PIN            PA2 //D9 сенсор напряжения 12В
#define VCC_DROP           112 //падение напряжения на диоде 0.6v/6.6/3.32

//DEFINE констант расходомера
#if defined(VZ)
#define Ncyl 6.0      //6 форсунок
#elif defined(RZ)
#define Ncyl 4.0        //4 форсунки
#else
#error “Unsupported Engine!!!”
#endif

#define FuelCapacity 90
//DEFINE OBD READER
#define  MY_HIGH  HIGH //LOW    // I have inverted the Eng line using an Opto-Coupler, if yours isn't then reverse these low & high defines.
#define  MY_LOW   LOW //HIGH
#define  TOYOTA_MAX_BYTES  24
#define OBD_INJ 0 //Injector pulse width (INJ)
#define OBD_IGN 1 //Ignition timing angle (IGN)
#define OBD_IAC 2 //Idle Air Control (IAC)
#define OBD_RPM 3 //Engine speed (RPM)
#define OBD_MAP 4 //Manifold Absolute Pressure (MAP)
#define OBD_ECT 5 //Engine Coolant Temperature (ECT)
#define OBD_TPS 6 // Throttle Position Sensor (TPS)
#define OBD_SPD 7 //Speed (SPD)
#define OBD_OXSENS 8 // Oxygen sensor 1

#ifdef SECOND_O2SENS    // Oxygen sensor 2
#define TOBD_ID_MAX 10
#define OBD_OXSENS2 9
const char* TOBD_ID_NAME[TOBD_ID_MAX] = {"INJ", "IGN", "IAC", "RPM", "MAF", "ECT", "TPS", "SPD", "VF1", "VF2"};
#else
#define TOBD_ID_MAX 9
const char* TOBD_ID_NAME[TOBD_ID_MAX] = {"INJ", "IGN", "IAC", "RPM", "MAF", "ECT", "TPS", "SPD", "VF"};
#endif

#define ILI9341_GREY 0x8410
#endif

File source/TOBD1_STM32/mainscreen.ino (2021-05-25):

void mainscreen(void) {
  tft.setTextColor(TEXT_COLOR);
  if (isActive == false) {                      //если первый раз экран появился то рисуются подписи
    tft.fillScreen(BG_COLOR);
    showtime();
    tft.setFont(&CPMono_v07_Light6pt7b );
    printpos(ADC.vcc_avg * VREF_MEASURED * VCC_PIN_DIVIDER / 4095.0, 1, 20, 30);
    printpos(F("TRIP FUEL"), 16, 90);
    printpos(F("COOLANT TEMP"), 16, 146);
    printpos(F("INSTANT FUEL"), 196, 90);
    printpos(F("AVERAGE TRIP"), 196, 146);
    printpos(F("TRIP"), 48, 209);
    tft.setFont(&CPMono_v07_Plain9pt7b );
    printpos(F("L"), 117, 120);
    printpos(F("C"), 117, 182);
    tft.drawCircle(111, 170, 3, TEXT_COLOR);
    printpos(F("LPK"), 270, 182);
    if (OBDDATA[OBD_SPD] > 1)       //если есть движение то литры на 100км
      printpos(F("LPK"), 270, 120);
    if (OBDDATA[OBD_SPD] < 1)   //если стоим то литры в час
      printpos(F("LPH"), 270, 120);
    tft.setFont(&DSEG7ModernMini_Bold13pt7b );
    printpos(trip_fuel_consumption, 1, 16, 120);
    if (OBDDATA[OBD_ECT] < 50)
      tft.setTextColor(BLUE_COLOR);
    else if (OBDDATA[OBD_ECT] < 99) tft.setTextColor(TEXT_COLOR);
    else tft.setTextColor(RED_COLOR);
    printpos(OBDDATA[OBD_ECT], 1, 16, 182);
    tft.setTextColor(TEXT_COLOR);
    if (OBDDATA[OBD_SPD] > 1)        //если есть движение то литры на 100км
      printpos(maindata[0], 1, 188, 120);
    else printpos(maindata[1], 1, 188, 120); //иначе литры в час
    if (trip_avg_fuel_consumption < 100)
      printpos(trip_avg_fuel_consumption, 1, 188, 182);
    else
      printpos(F("99.9"), 188, 182);
    tft.drawRoundRect(8, 75, 128, 55, 12, RED_COLOR);
    tft.drawRoundRect(8, 134, 128, 55, 12, RED_COLOR);
    tft.drawRoundRect(184, 75, 130, 55, 12, RED_COLOR);
    tft.drawRoundRect(184, 134, 130, 55, 12, RED_COLOR);
    if (OBDDATA[OBD_SPD] < 1) {
      neutral();
    } else {
      show_current_gear(); //принудительная перерисовка
    }
    isActive = true;
  }// если экран не меняется то подписи не обновляются
  // if (OBDDATA[OBD_SPD] < 1) {
  //   neutral();
  // } else
  // { //только при движении
  //  show_current_gear(false); //только при изменении передачи
  //}
  //TT.last = TT.current;
  maindata[0] = 100  * (OBDDATA[OBD_INJ] * OBDDATA[OBD_RPM] / OBDDATA[OBD_SPD] * Ls / 1000 / 2 * 60 * Ncyl);  //LPK
  if (maindata[0] > 100.0f) maindata[0] = 99.9;                       //если больше 100 то выводить 99.9
  maindata[1] = OBDDATA[OBD_INJ] * OBDDATA[OBD_RPM] * Ls / 1000 / 2 * 60 * Ncyl;    //LPH
  if (maindata[1] > 100.0f) maindata[1] = 99.9;                       //если больше 100 то выводить 99.9
  maindata[2] = trip_avg_fuel_consumption;
  if (maindata[2] > 100.0f) maindata[2] = 99.9;                       //если больше 100 то выводить 99.9
  maindata[3] = trip_fuel_consumption;
  if (maindata[3] > 100.0f) maindata[3] = 99.9;                       //если больше 100 то выводить 99.9
  maindata[4] = ADC.vcc_avg * VREF_MEASURED * VCC_PIN_DIVIDER / 4095.0;
  tft.setTextColor(TEXT_COLOR);
  if (fabs(maindata[4] - maindataold[4]) > 0.09)
  {
    tft.setFont(&CPMono_v07_Light6pt7b );
    tft.fillRect(20, 0, 40, 30, BG_COLOR);
    printpos(maindata[4], 1, 20, 30);
    maindataold[4] = maindata[4];
  }
  tft.setFont(&CPMono_v07_Light6pt7b );
  if (flag.isTrip) {
    if (!flag.TripActive) {
      tft.setFont(&CPMono_v07_Light6pt7b );
      tft.fillRect(16, 82, 100, 12, BG_COLOR);
      printpos(F("TRIP FUEL"), 16, 90);
      tft.fillRect(231, 196, 40, 19, BG_COLOR);
      printpos(F("KM"), 234, 209);
      flag.TripActive = true;
      tft.setFont(&DSEG7ModernMini_Bold13pt7b );
      tft.fillRect(16, 95, 100, 27, BG_COLOR);
      printpos(trip_fuel_consumption, 1, 16, 120);
      tft.fillRect(85, 196, 145, 37, BG_COLOR);
      printpos(F("   "), 90, 225);
      if (trip_km < 10)
        printpos(F("000"), 90, 225);
      else if (trip_km < 100)
        printpos(F("00"), 90, 225);
      else if (trip_km < 1000)
        printpos(F("0"), 90, 225);
      tft.print(trip_km, 1);
    }
    if (fabs(maindata[3] - maindataold[3]) > 0.09)
    {
      tft.setFont(&DSEG7ModernMini_Bold13pt7b );
      tft.fillRect(16, 95, 90, 27, BG_COLOR);
      printpos(maindata[3], 1, 16, 120);
      maindataold[3] = maindata[3];
    }
  }
  if (!flag.isTrip) {
    if (!flag.TripActive) {
      tft.setFont(&CPMono_v07_Light6pt7b );
      tft.fillRect(16, 82, 100, 12, BG_COLOR);
      printpos(F("FUEL REMAINS"), 16, 90);
      tft.fillRect(231, 196, 40, 19, BG_COLOR);
      printpos(F("TIME"), 234, 209);
      tft.setFont(&DSEG7ModernMini_Bold13pt7b );
      tft.fillRect(16, 95, 100, 27, BG_COLOR);
      printpos(fuel.remains, 1, 16, 120);
      tft.fillRect(85, 196, 145, 37, BG_COLOR);
      printpos(TimeToString(trip_time), 90, 225);
      flag.TripActive = true;
    }
    tft.setFont(&DSEG7ModernMini_Bold13pt7b );
    tft.fillRect(16, 95, 90, 27, BG_COLOR);
    printpos(fuel.remains, 1, 16, 120);
  }
  if (OBDDATA[OBD_ECT] < 50)
    tft.setTextColor(BLUE_COLOR);
  else if (OBDDATA[OBD_ECT] < 99) tft.setTextColor(TEXT_COLOR);
  else tft.setTextColor(RED_COLOR);

  if (fabs(OBDDATA[OBD_ECT] - OLDOBDDATA[OBD_ECT]) > 0.09)
  {
    tft.setFont(&DSEG7ModernMini_Bold13pt7b );
    tft.fillRect(16, 157, 90, 27, BG_COLOR);
    printpos(OBDDATA[OBD_ECT], 1, 16, 182);
  }
  tft.setTextColor(TEXT_COLOR);
  if (OBDDATA[OBD_SPD] > 1)       //если есть движение то литры на 100км
  {
    if (_isLPK == false)          //смена экрана  - перерисовка надписи и значений
    {
      tft.setFont(&CPMono_v07_Plain9pt7b );
      send_tft2(F("LPK"), 12, 40, 270, 120);
      tft.setFont(&DSEG7ModernMini_Bold13pt7b );
      tft.fillRect(188, 95, 82, 27, BG_COLOR);
      printpos(maindata[0], 1, 188, 120);
      _isLPK = true;
    }
    if (fabs(maindata[0] - maindataold[0]) > 0.09)  //перерисовка значений только если отличаются на 0.1
    {
      tft.setFont(&DSEG7ModernMini_Bold13pt7b );
      tft.fillRect(188, 95, 82, 27, BG_COLOR);
      printpos(maindata[0], 1, 188, 120);
      maindataold[0] = maindata[0];
    }
  }
  if (OBDDATA[OBD_SPD] < 1)   //если стоим то литры в час
  {
    if (_isLPK == true)         //смена экрана  - перерисовка надписи и значений
    {
      tft.setFont(&CPMono_v07_Plain9pt7b );
      send_tft2(F("LPH"), 12, 40, 270, 120);
      tft.setFont(&DSEG7ModernMini_Bold13pt7b );
      tft.fillRect(188, 95, 82, 27, BG_COLOR);
      printpos(maindata[1], 1, 188, 120);
      _isLPK = false;
    }
    if (fabs(maindata[1] - maindataold[1]) > 0.09) //перерисовка значений только если отличаются на 0.1
    {
      tft.setFont(&DSEG7ModernMini_Bold13pt7b );
      tft.fillRect(188, 95, 82, 27, BG_COLOR);
      printpos(maindata[1], 1, 188, 120);
      maindataold[1] = maindata[1];
    }
  }
  if (fabs(maindata[2] - maindataold[2]) > 0.09)
  {
    tft.setFont(&DSEG7ModernMini_Bold13pt7b );
    tft.fillRect(188, 157, 82, 27, BG_COLOR);
    printpos(maindata[2], 1, 188, 182);
    maindataold[2] = maindata[2];
  }
  showtime();
  }

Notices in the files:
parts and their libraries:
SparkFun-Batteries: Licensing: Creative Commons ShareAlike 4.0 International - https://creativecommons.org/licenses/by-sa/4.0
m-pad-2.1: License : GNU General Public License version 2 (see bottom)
